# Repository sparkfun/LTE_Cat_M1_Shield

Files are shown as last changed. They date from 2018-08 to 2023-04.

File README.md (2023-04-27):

SparkFun LTE CAT M1/NB-IoT Shield - SARA-R4
========================================

SparkFun LTE CAT M1/NB-IoT Shield - SARA-R4 (https://www.sparkfun.com/products/14997)

[*SparkFun LTE CAT M1/NB-IoT Shield - SARA-R4 (CEL-14997)*](https://www.sparkfun.com/products/14997)

Arduino shield featuring a SARA-R410M-02B module, which supports both Cat M1 and NB-IoT

Repository Contents
-------------------

* **/Documentation** - Data sheets, additional product information
* **/Hardware** - Eagle design files (.brd, .sch)
* **/Production** - Production panel files (.brd)

Documentation
--------------
* **[Installing an Arduino Library Guide](https://learn.sparkfun.com/tutorials/installing-an-arduino-library)** - Basic information on how to install an Arduino library.
* **[Library](https://github.com/sparkfun/SparkFun_LTE_Shield_Arduino_Library)** - Arduino library.
* **[Hookup Guide](https://learn.sparkfun.com/tutorials/lte-cat-m1nb-iot-shield-hookup-guide)** - Basic hookup guide.

Version History
---------------
* v11 - Removed `GND` connection to `AREF` pin
* [v10](https://github.com/sparkfun/LTE_Cat_M1_Shield/releases/tag/v10) - Initial Release

License Information
-------------------

This product is _**open source**_! 

Various bits of the code have different licenses applied. Anything SparkFun wrote is beerware; if you see me (or any other SparkFun employee) at the local, and you've found our code helpful, please buy us a round!

Please use, reuse, and modify these files as you see fit. Please maintain attribution to SparkFun Electronics and release anything derivative under the same license.

Distributed as-is; no warranty is given.

- Your friends at SparkFun.

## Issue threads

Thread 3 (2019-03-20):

Both Sides of TVS tied to ground

method-nick, 2019-03-20:
I'm curious about your wiring of the TVS diode on the SIM card. By connecting both GND and VCC of the diode to the PCB ground the signals can't won't be able to get above the forward voltage of the diodes (1V).

I think the VCC pin of the diode should be connected to the 3V3 rail for correct operation.

lewispg228, 2019-12-09:
Hi @method-nick

Thanks for bringing this up. Sorry our response is so slow on this. Sorry for the confusion, but the part value in the schematic for this (v10) is incorrect.

The part shown in the schematic is "DT1042-04SO"
[DT1042-04SO datasheet](https://www.diodes.com/assets/Datasheets/DT1042-04SO.pdf)

This part is normally used as a unidirectional TVS circuit (which involves connecting to VCC).

In production we are populating a different part. We are actually using the "ESDA6V1BC6".
[ESDA6V1BC6 datasheet](https://static6.arrow.com/aropdfconversion/8da17f9020eacc1aa29eff2b41ce2f0dfe2e4561/cd0000190.pdf)

This part is used as a bidirectional TVS circuit, and so both pins 2 and 5 of the IC are intended to be connected to GND.

I found some interested articles regarding TVS circuits, if you'd like to read more on this:

[TI FORUM: Should TVS diodes be connected on the Vcc side](https://e2e.ti.com/support/interface/f/138/t/710604)

[TI APP NOTE: Design considerations for system-level
ESD circuit protection](https://www.ti.com/lit/an/slyt492/slyt492.pdf)
(particularly page 3, which describes the difference between unidirectional and bidirection TVS circuits)

Thanks again and we will work to get the part name in the schematic updated in v10 asap.
-Pete

Closed 2019-12-09.

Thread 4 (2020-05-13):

Use as cellular modem

sagilar, 2020-05-13:
I like to ask if there is the possibility to use the shield as a cellular modem, to provide connectivity, even if it is very slow, just to access services on the web.
I am using a board similar to a Raspberry PI, and I'd like to integrate this shield with the board to get internet access via the cellular module, and then, create a bridge between this interface (either via USB or Serial) and the wireless interface wlan0. So, I could set up a Wireless Access Point between cellular interface and WiFi.

Thanks for your answer.

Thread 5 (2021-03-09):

Teensy 4.x + SARA-R410 + TinyGSM + SSLClient  = failed mTLS connections?

MaffooClock, 2021-03-09:
I'm prototyping a project that is designed to communicate with [AWS IoT MQTT](https://docs.aws.amazon.com/iot/latest/developerguide/mqtt.html) via cellular IoT.  Using the MQTT service through AWS means mTLS is required, and the only library that can provide that for Arduino is [SSLClient](https://github.com/OPEnSLab-OSU/SSLClient).

It seems that when combining a u-blox SARA-R410 (or, perhaps more specifically, this SparkFun shield) with a Teensy 4.x, mTLS connections never complete.  I opened[ issue #33](https://github.com/OPEnSLab-OSU/SSLClient/issues/33) with SSLClient thinking the problem was with the library, but after switching to another modem (same codebase), the problem went away.

I've used the same SARA-R410 with other Arduinos (SAMD21 and SAM3X MCUs) with the same codebase with plenty of success, but for some strange reason, this particular shield seemed to cause a problem with SSLClient on the Teensy 4.x.

The only reason I'm opening this issue is just in case someone else happens to experience the same trouble I did with the same environment.  Maybe this is a highly unique situation that only I will ever experience, or perhaps my SparkFun shield is somehow defective (unlikely, seems to work fine otherwise), but I figured I had an obligation to share.

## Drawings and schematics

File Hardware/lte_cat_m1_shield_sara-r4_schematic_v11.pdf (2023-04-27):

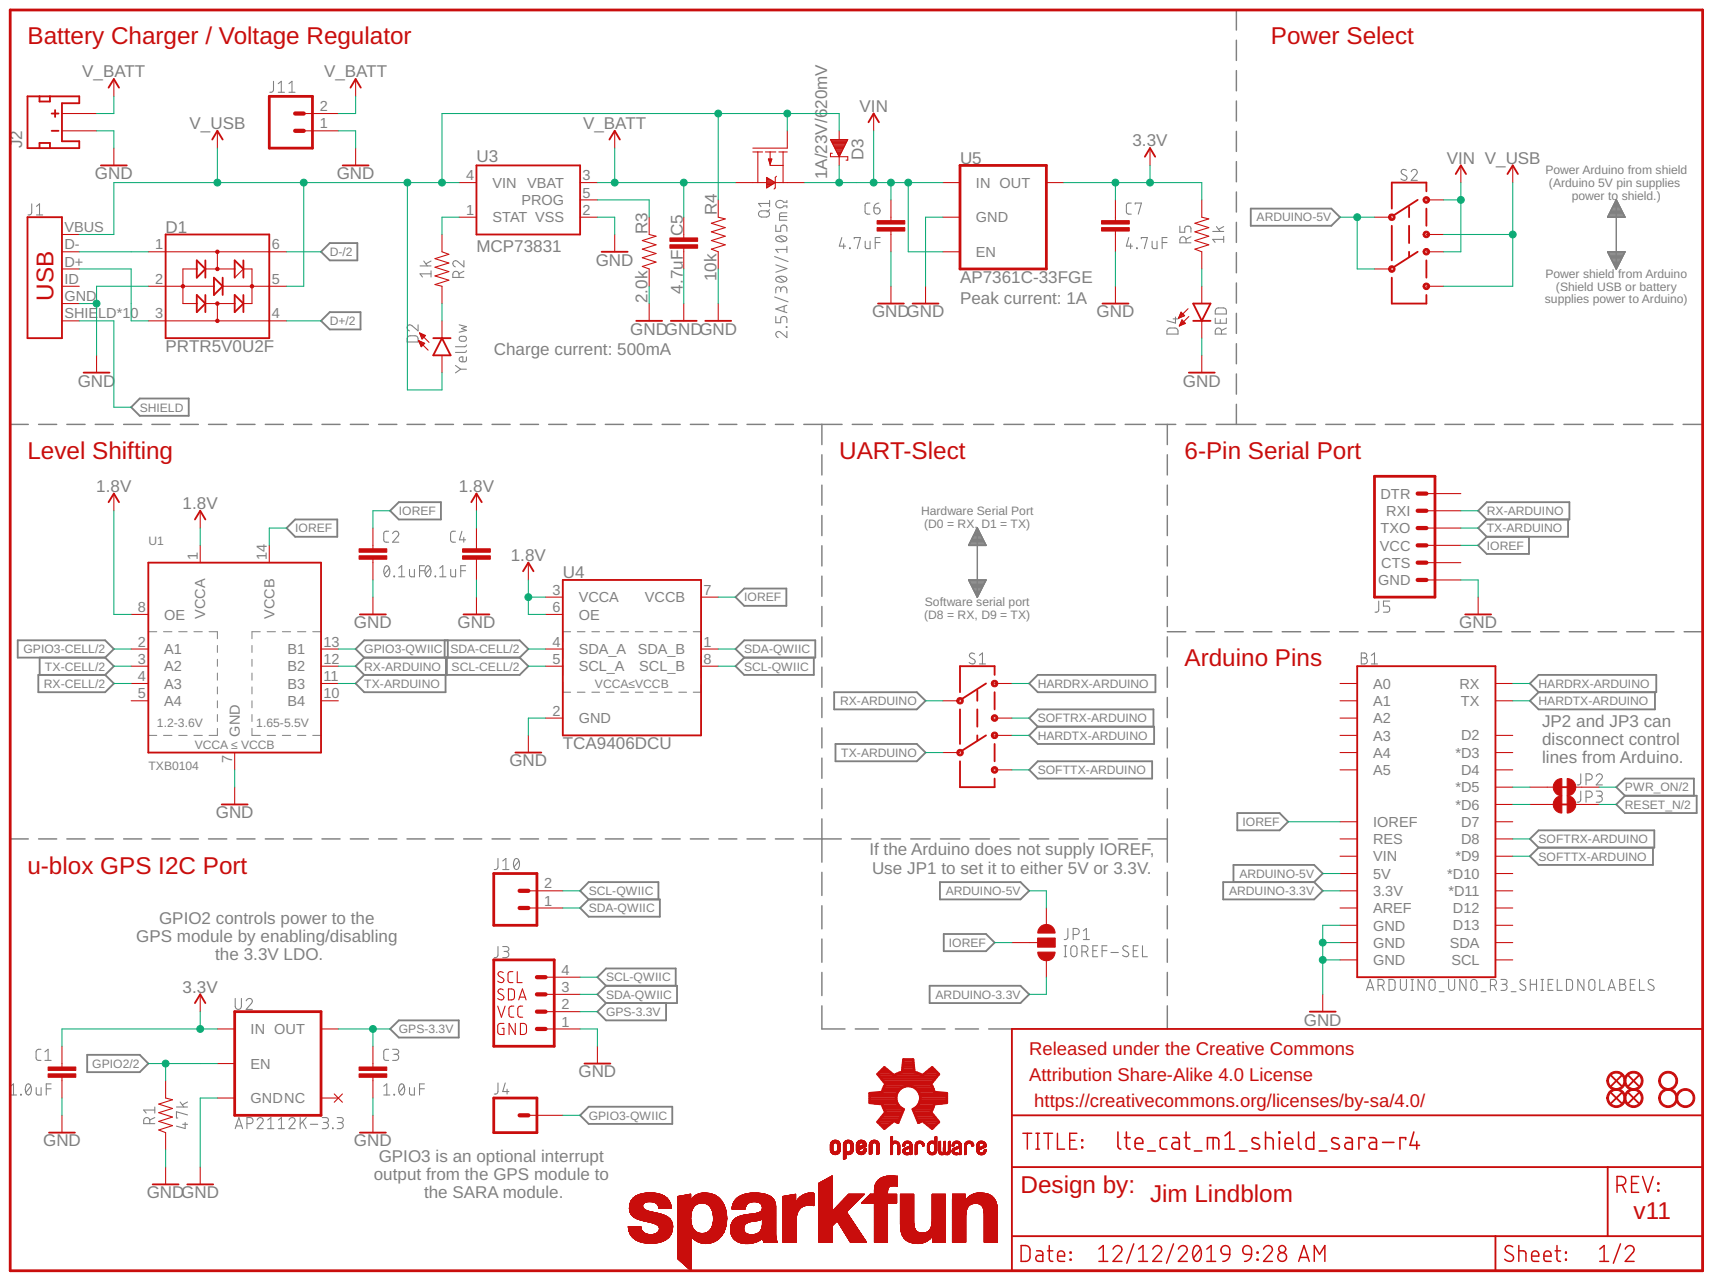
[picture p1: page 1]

Power Arduino from shield
(Arduino 5V pin supplies power to shield.) Power shield from Arduino

(Shield USB or battery
supplies power to Arduino)

Hardware Serial Port (D0 = RX, D1 = TX) Software serial port (D8 = RX, D9 = TX)

If the Arduino does not supply IOREF, Use JP1 to set it to either 5V or 3.3V. GPIO2 controls power to the GPS module by enabling/disabling

Released under the Creative Commons
Attribution Share-Alike 4.0 License
https://creativecommons.org/licenses/by-sa/4.0/

GPIO3 is an optional interrupt output from the GPS module to

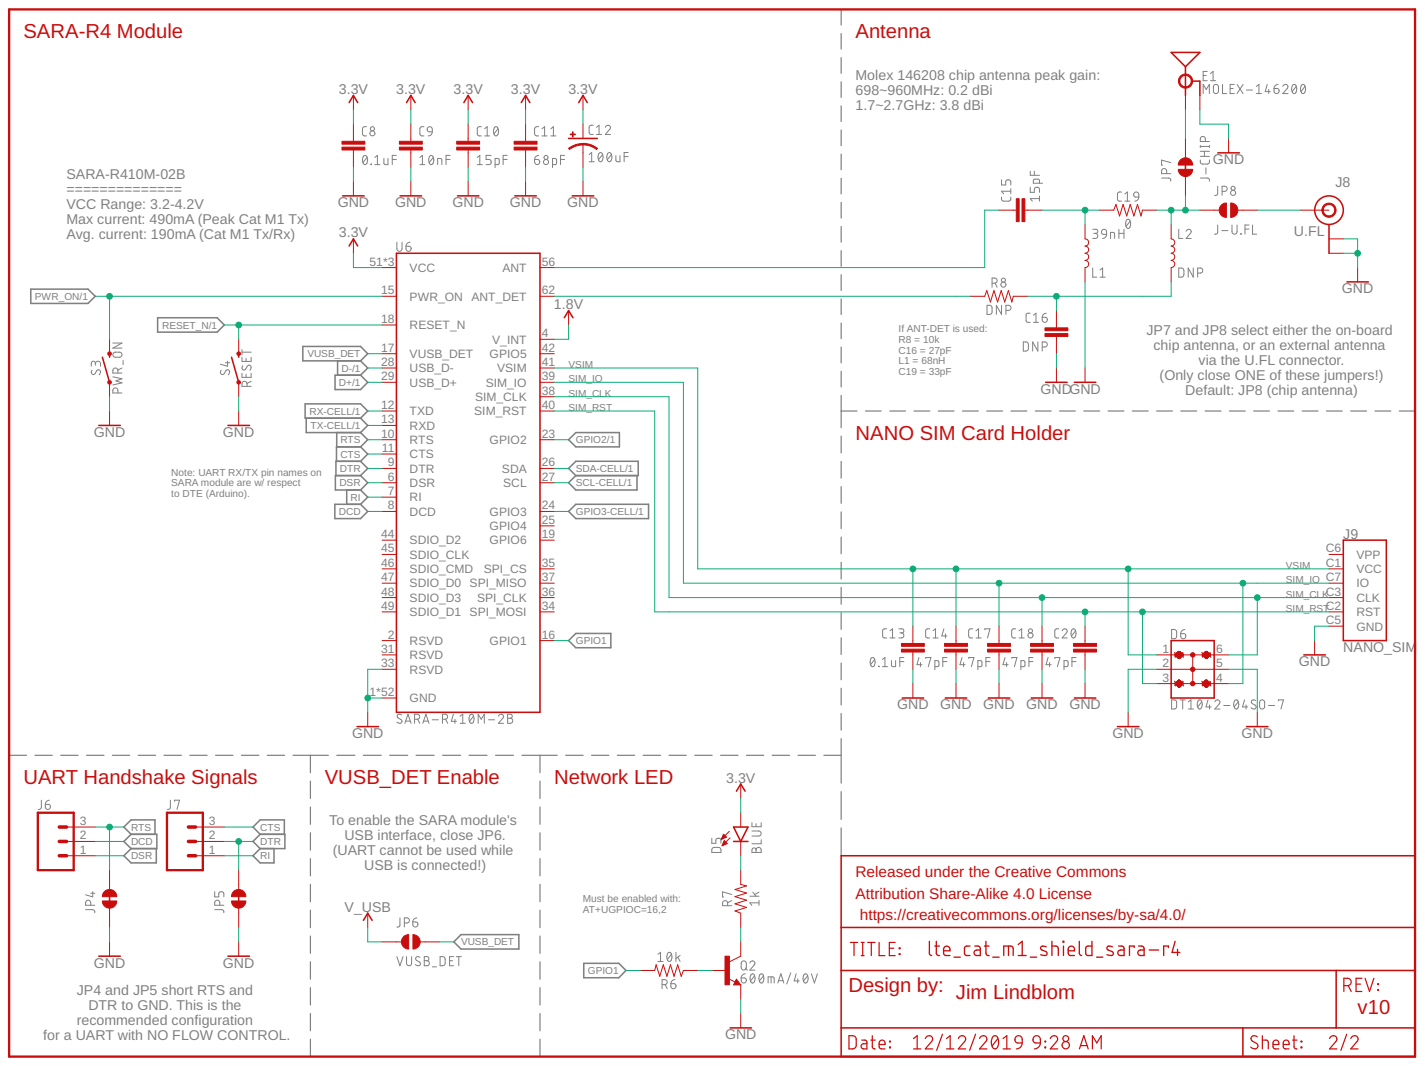
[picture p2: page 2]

Molex 146208 chip antenna peak gain: 698~960MHz: 0.2 dBi

Max current: 490mA (Peak Cat M1 Tx)
Avg. current: 190mA (Cat M1 Tx/Rx)

If ANT-DET is used: R8 = 10k C16 = 27pF

JP7 and JP8 select either the on-board
chip antenna, or an external antenna
via the U.FL connector. (Only close ONE of these jumpers!)

Default: JP8 (chip antenna) Note: UART RX/TX pin names on SARA module are w/ respect

NANO SIM Card Holder

GND GND GND GND GND

To enable the SARA module's USB interface, close JP6. (UART cannot be used while USB is connected!)

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

Must be enabled with: AT+UGPIOC=16,2

JP4 and JP5 short RTS and
DTR to GND. This is the
recommended configuration
for a UART with NO FLOW CONTROL.

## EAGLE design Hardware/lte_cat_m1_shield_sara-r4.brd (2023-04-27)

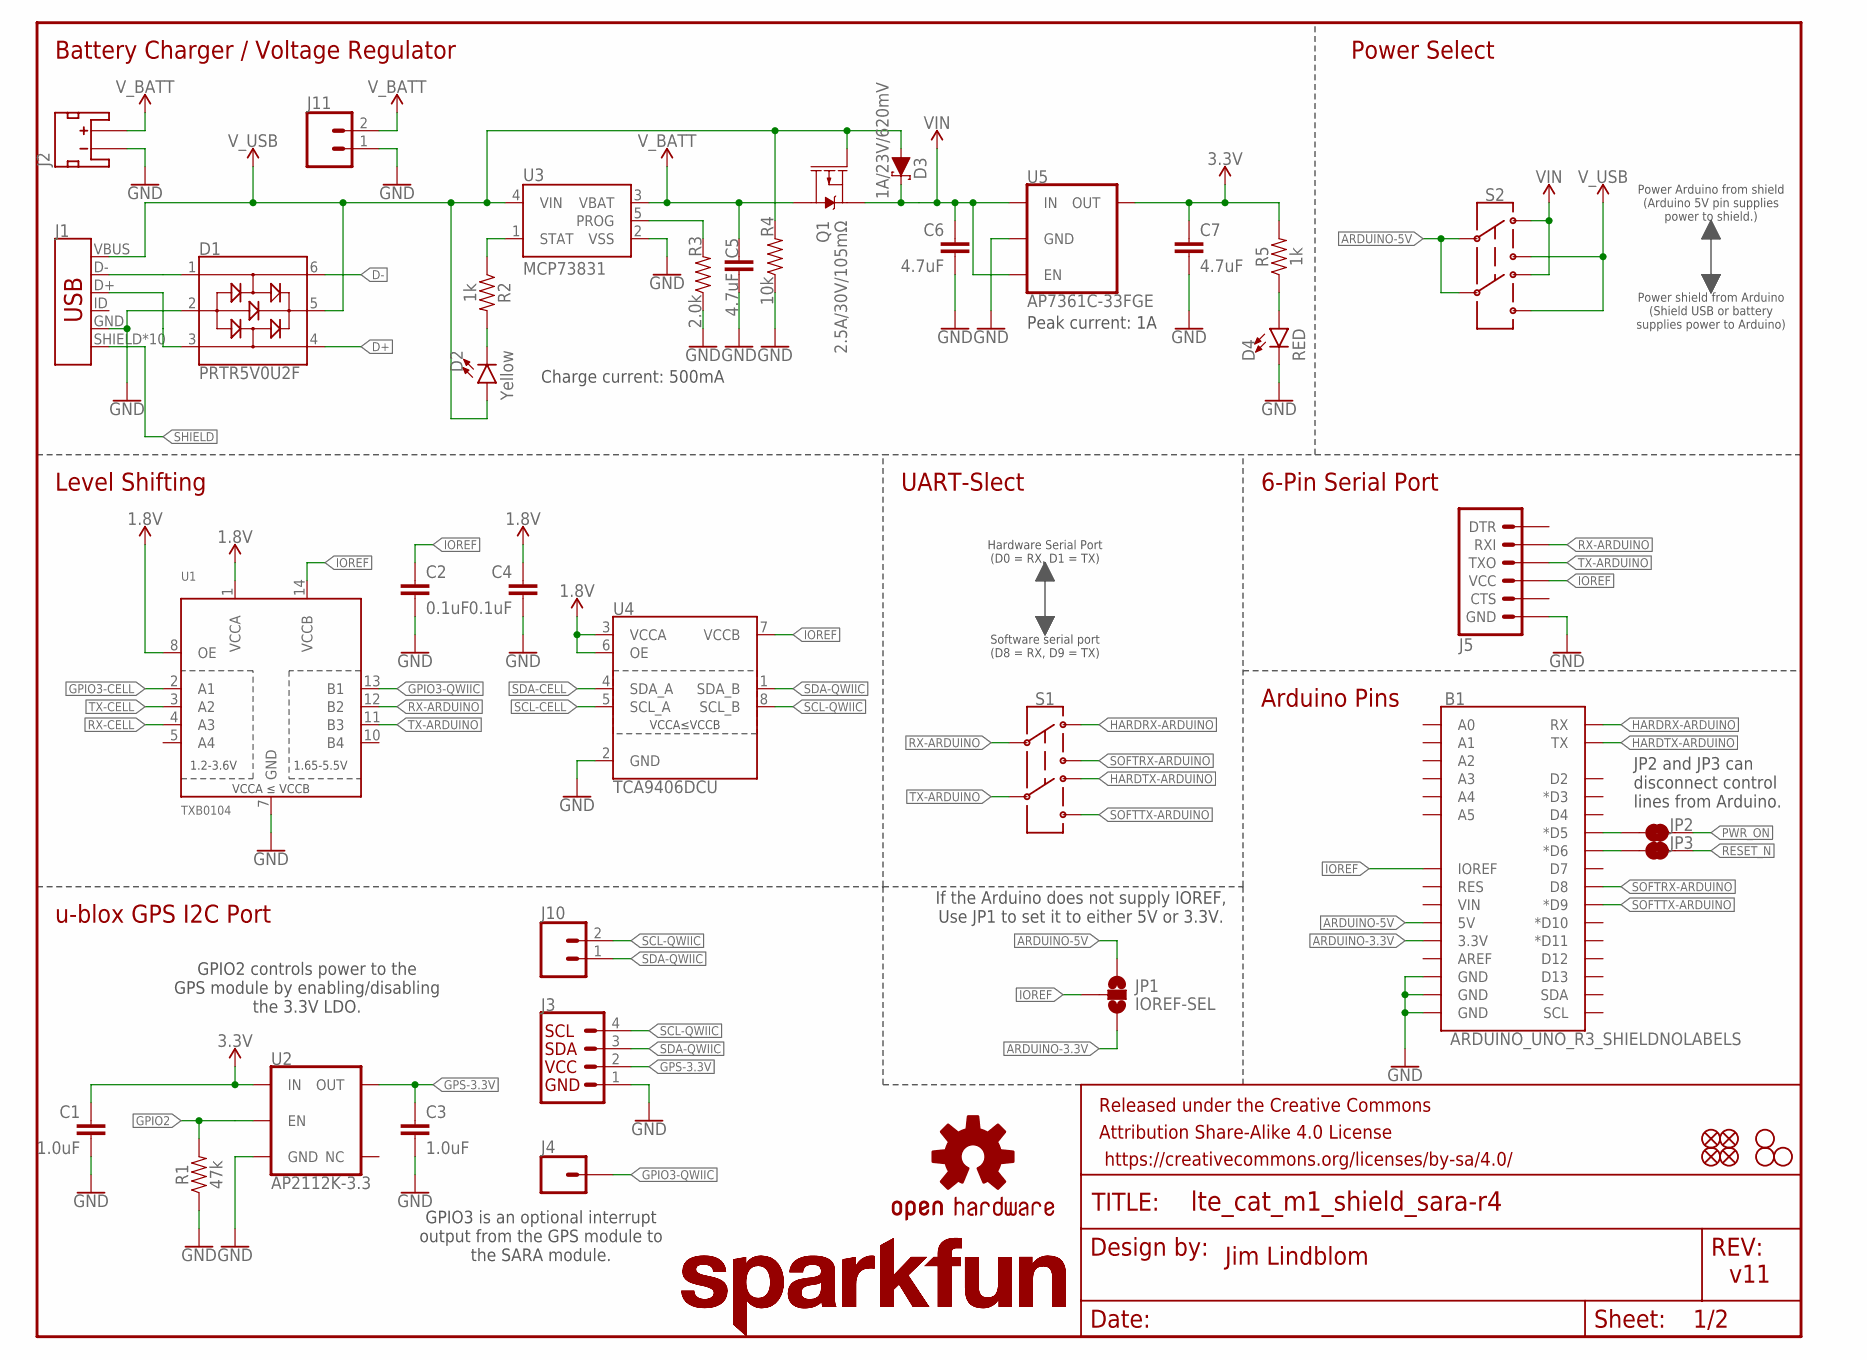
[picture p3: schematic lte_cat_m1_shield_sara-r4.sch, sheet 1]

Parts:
B1: ARDUINO_UNO_R3_SHIELDNOLABELS; UNO_R3_SHIELD_NOLABELS
C1, C3: 1.0uF; 0603
C2, C4: 0.1uF; 0603
C5, C6, C7: 4.7uF; 0603
D1: PRTR5V0U2F; SOT886
D2: Yellow; LED-0603
D3: 1A/23V/620mV; SOD-323
D4: RED; LED-0603
FD1, FD2, FD3, FD4: FIDUCIALUFIDUCIAL; FIDUCIAL-MICRO
FRAME1: FRAME-LETTER; CREATIVE_COMMONS
H1, H2, H3: STAND-OFF
J1: USB_MICRO-B_HALF_PTH_MILL; USB-MICROB-PTH-MILL
J2: JST_2MM_MALESMD; JST-2-SMD
J3: QWIIC_CONNECTORJS-1MM; 1X04_1MM_RA
J4: CONN_01PTH_NO_SILK_YES_STOP; 1X01_NO_SILK
J5: 6_PIN_SERIAL_TARGETNO_SILK; 1X06_NO_SILK
J10, J11: CONN_021X02_NO_SILK; 1X02_NO_SILK
JP1: IOREF-SEL; SMT-JUMPER_3_NO_SILK
JP2, JP3: JUMPER-SMT_2_NC_TRACE_SILK; SMT-JUMPER_2_NC_TRACE_SILK
LOGO1, LOGO3: SFE_LOGO_NAME.2_INCH; SFE_LOGO_NAME_.2
LOGO2: OSHW-LOGOM; OSHW-LOGO-M
Q1: 2.5A/30V/105mΩ; SOT23-3
R1: 47k; 0603
R2, R5: 1k; 0603
R3: 2.0k; 0603
R4: 10k; 0603
S1, S2: SWITCH-DPDT-SMD-AYZ0202; SWITCH_DPDT_SMD_AYZ0202
U1: TXB0104; TSSOP14
U2: AP2112K-3.3; SOT23-5
U3: MCP73831; SOT23-5
U4: TCA9406DCU; VSSOP-8
U5: AP7361C-33FGE; 8-UDFN

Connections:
1.8V: C4.1, U1.1 (VCCA), U1.8 (OE), U4.3 (VCCA), U4.6 (OE); also elsewhere on the board
3.3V: C1.1, C7.1, R5.2, U2.1 (IN), U5.1 (OUT); also elsewhere on the board
ARDUINO-3.3V: B1.3.3V, JP1.3
ARDUINO-5V: B1.5V, JP1.1, S2.2, S2.5
D+: D1.4; also elsewhere on the board
D-: D1.6; also elsewhere on the board
GND: B1.GND@0 (GND), B1.GND@1 (GND), B1.GND@2 (GND), C1.2, C2.2, C3.2, C4.2, C5.2, C6.2, C7.2, D1.2, D4.C, J1.GND, J2.1 (-), J3.1, J5.6 (GND), J11.1, R1.1, R3.1, R4.1, U1.7 (GND), U2.2 (GND), U3.2 (VSS), U4.2 (GND), U5.4 (GND), U5.EP (GND); also elsewhere on the board
GPIO2: R1.2, U2.3 (EN); also elsewhere on the board
GPIO3-CELL: U1.2 (A1); also elsewhere on the board
GPIO3-QWIIC: J4.1, U1.13 (B1)
GPS-3.3V: C3.1, J3.2, U2.5 (OUT)
HARDRX-ARDUINO: B1.RX, S1.1
HARDTX-ARDUINO: B1.TX, S1.4
IOREF: B1.IOREF, C2.1, J5.4 (VCC), JP1.2, U1.14 (VCCB), U4.7 (VCCB)
unnamed: R3.2, U3.5 (PROG)
unnamed: D1.1, J1.D-
unnamed: D1.3, J1.D+
unnamed: D4.A, R5.1
unnamed: D2.C, R2.2
unnamed: R2.1, U3.1 (STAT)
unnamed: B1.D5 (*D5), JP2.1
unnamed: B1.D6 (*D6), JP3.1
PWR_ON: JP2.2; also elsewhere on the board
RESET_N: JP3.2; also elsewhere on the board
RX-ARDUINO: J5.2 (RXI), S1.2, U1.12 (B2)
RX-CELL: U1.4 (A3); also elsewhere on the board
SCL-CELL: U4.5 (SCL_A); also elsewhere on the board
SCL-QWIIC: J3.4, J10.2, U4.8 (SCL_B)
SDA-CELL: U4.4 (SDA_A); also elsewhere on the board
SDA-QWIIC: J3.3, J10.1, U4.1 (SDA_B)
SHIELD: J1.SHIELD, J1.SHIELD2 (SHIELD), J1.SHIELD3 (SHIELD), J1.SHIELD4 (SHIELD), J1.SHIELD5 (SHIELD), J1.SHIELD6 (SHIELD), J1.SHIELD7 (SHIELD), J1.SHIELD8 (SHIELD), J1.SHIELD9 (SHIELD), J1.SHIELD10 (SHIELD)
SOFTRX-ARDUINO: B1.D8, S1.3
SOFTTX-ARDUINO: B1.D9 (*D9), S1.6
TX-ARDUINO: J5.3 (TXO), S1.5, U1.11 (B3)
TX-CELL: U1.3 (A2); also elsewhere on the board
VIN: C6.1, D3.C, Q1.2 (S), S2.1, S2.4, U5.5 (EN), U5.8 (IN)
V_BATT: C5.1, J2.2 (+), J11.2, Q1.3 (D), U3.3 (VBAT)
V_USB: D1.5, D2.A, D3.A, J1.VBUS, Q1.1 (G), R4.2, S2.3, S2.6, U3.4 (VIN); also elsewhere on the board

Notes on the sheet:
Charge current: 500mA
Power Arduino from shield (Arduino 5V pin supplies power to shield.)
Power shield from Arduino (Shield USB or battery supplies power to Arduino)
Battery Charger / Voltage Regulator
Power Select
Level Shifting
If the Arduino does not supply IOREF, Use JP1 to set it to either 5V or 3.3V.
u-blox GPS I2C Port
GPIO2 controls power to the GPS module by enabling/disabling the 3.3V LDO.
GPIO3 is an optional interrupt output from the GPS module to the SARA module.
UART-Slect
6-Pin Serial Port
Arduino Pins
Jim Lindblom
v11
Peak current: 1A
Hardware Serial Port (D0 = RX, D1 = TX)
Software serial port (D8 = RX, D9 = TX)
JP2 and JP3 can disconnect control lines from Arduino.

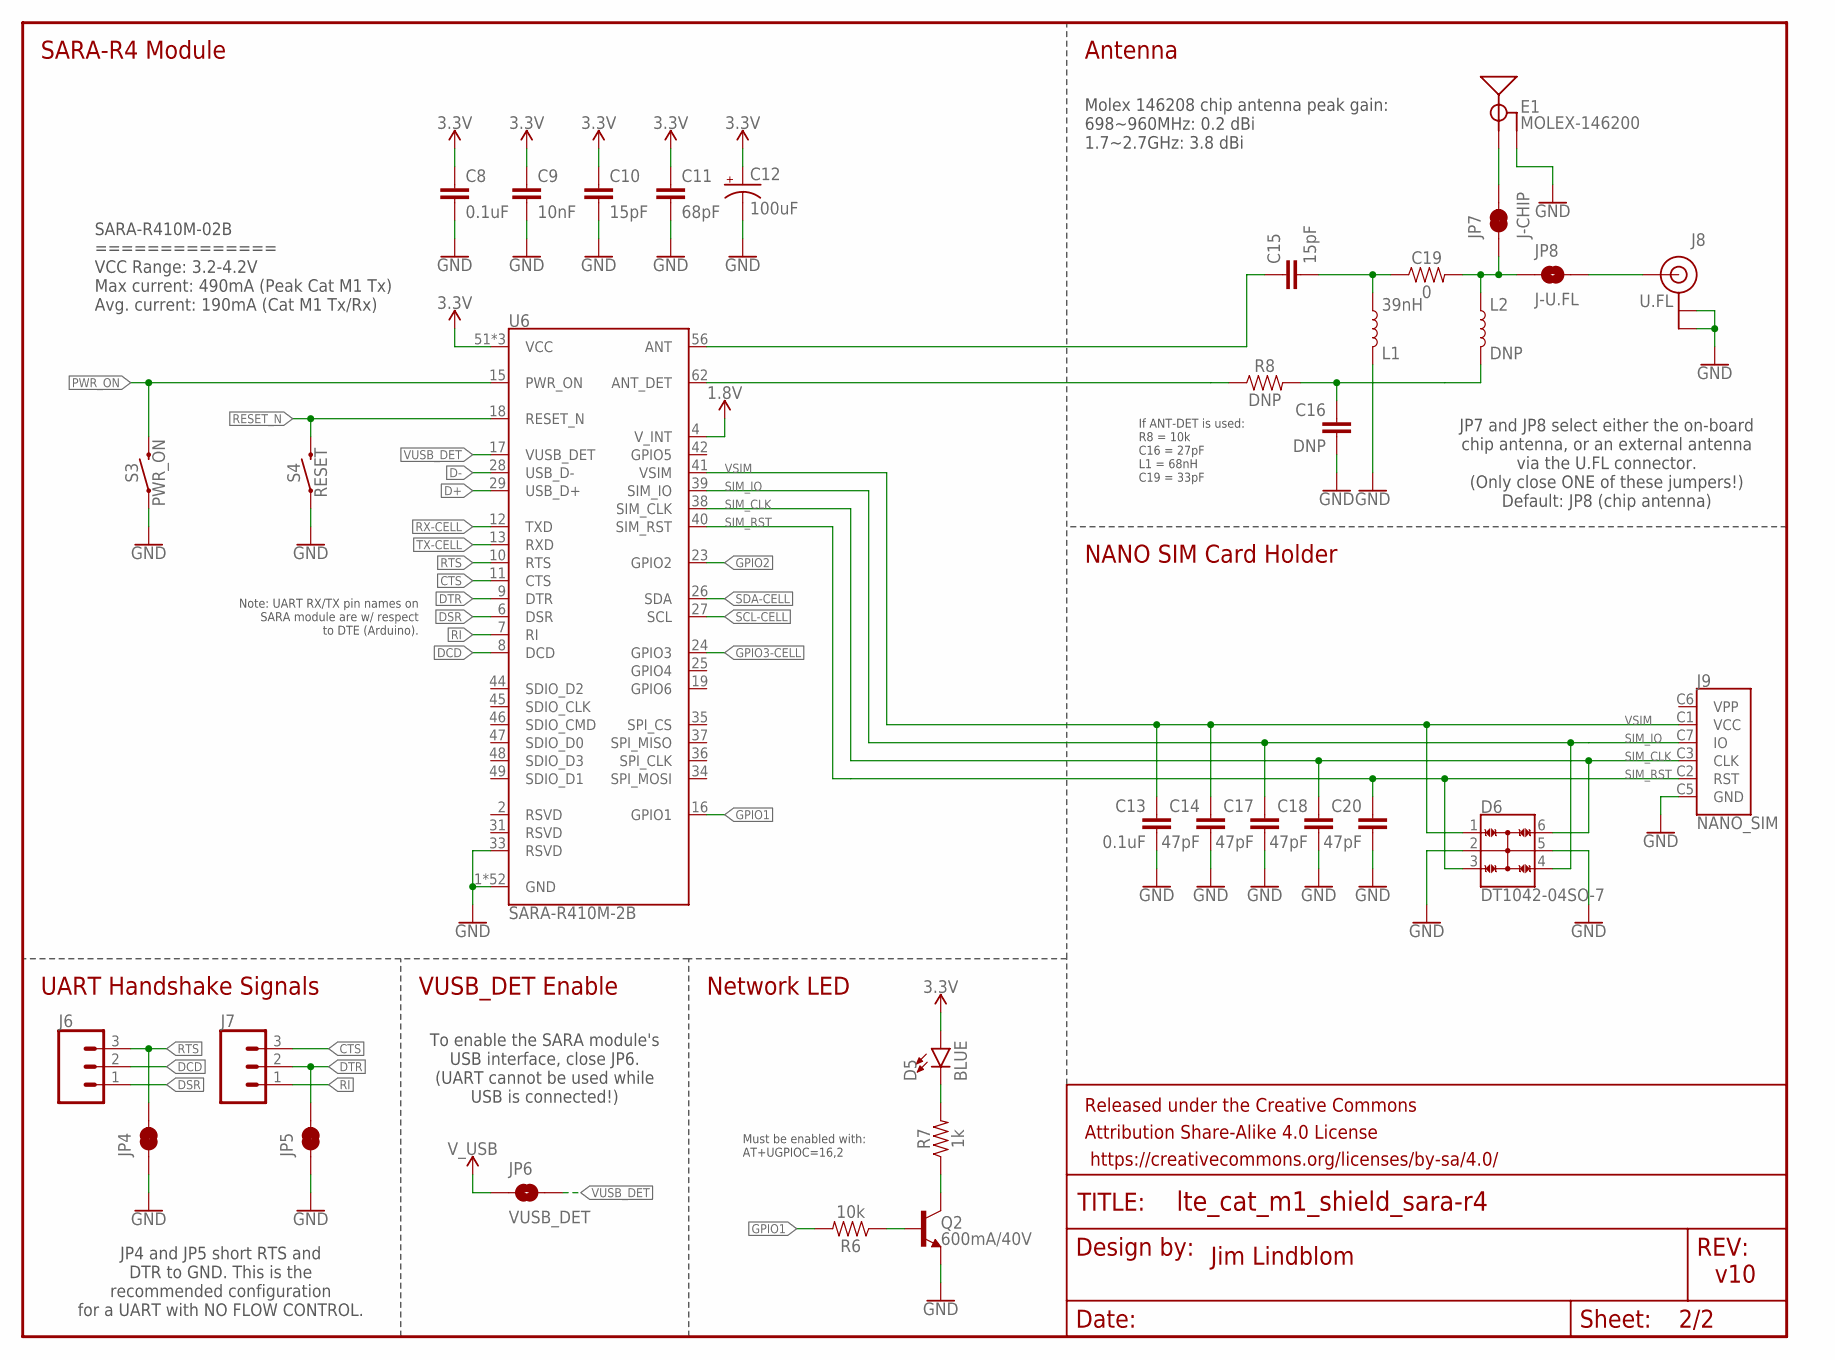
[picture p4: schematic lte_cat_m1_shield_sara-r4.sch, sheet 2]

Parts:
C8, C13: 0.1uF; 0603
C9: 10nF; 0603
C10, C15: 15pF; 0603
C11: 68pF; 0603
C12: 100uF; 1206-POLAR
C14, C17, C18, C20: 47pF; 0603
C16: DNP; 0603
C19: 0; 0603
D5: BLUE; LED-0603
D6: DT1042-04SO-7; SOT23-6L
E1: MOLEX-146200; MOLEX_146200
FRAME2: FRAME-LETTER; CREATIVE_COMMONS
J6, J7: CONN_031X03_NO_SILK; 1X03_NO_SILK
J8: U.FL
J9: NANO_SIM; NANO_SIM_WURTH_693043020611
JP4, JP5: JUMPER-SMT_2_NC_TRACE_SILK; SMT-JUMPER_2_NC_TRACE_SILK
JP6: VUSB_DET; SMT-JUMPER_2_NO_SILK
JP7: J-CHIP; SMT-JUMPER_2_NC_TRACE_NO-SILK
JP8: J-U.FL; SMT-JUMPER_2_NO_NO-SILK
L1: 39nH; 0603
L2: DNP; 0603
Q2: 600mA/40V; SOT23-3
R6: 10k; 0603
R7: 1k; 0603
R8: DNP; 0603
S3: PWR_ON; TACTILE_SWITCH_SMD_5.2MM
S4: RESET; TACTILE_SWITCH_SMD_5.2MM
U6: SARA-R410M-2B; SARA-LGA

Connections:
1.8V: U6.4 (V_INT); also elsewhere on the board
3.3V: C8.1, C9.1, C10.1, C11.1, C12.1 (+), D5.A, U6.51 (VCC), U6.52 (VCC), U6.53 (VCC); also elsewhere on the board
ANT: C15.1, U6.56 (ANT)
ANT_DET: R8.1, U6.62 (ANT_DET)
CTS: J7.3, U6.11 (CTS)
D+: U6.29 (USB_D+); also elsewhere on the board
D-: U6.28 (USB_D-); also elsewhere on the board
DCD: J6.2, U6.8 (DCD)
DSR: J6.1, U6.6 (DSR)
DTR: J7.2, JP5.2, U6.9 (DTR)
GND: C8.2, C9.2, C10.2, C11.2, C12.2 (-), C13.2, C14.2, C16.2, C17.2, C18.2, C20.2, D6.2, D6.5, E1.GND, J8.1 (GND), J8.2 (GND), J9.C5 (GND), JP4.1, JP5.1, L1.1, Q2.2 (E), S3.1, S3.2 (1), S4.1, S4.2 (1), U6.1 (GND), U6.3 (GND), U6.5 (GND), U6.14 (GND), U6.20 (GND), U6.21 (GND), U6.22 (GND), U6.30 (GND), U6.32 (GND), U6.33 (RSVD), U6.43 (GND), U6.50 (GND), U6.54 (GND), U6.55 (GND), U6.57 (GND), U6.58 (GND), U6.59 (GND), U6.60 (GND), U6.61 (GND), U6.63 (GND), U6.64 (GND), U6.65 (GND), U6.66 (GND), U6.67 (GND), U6.68 (GND), U6.69 (GND), U6.70 (GND), U6.71 (GND), U6.72 (GND), U6.73 (GND), U6.74 (GND), U6.75 (GND), U6.76 (GND), U6.77 (GND), U6.78 (GND), U6.79 (GND), U6.80 (GND), U6.81 (GND), U6.82 (GND), U6.83 (GND), U6.84 (GND), U6.85 (GND), U6.86 (GND), U6.87 (GND), U6.88 (GND), U6.89 (GND), U6.90 (GND), U6.91 (GND), U6.92 (GND), U6.93 (GND), U6.94 (GND), U6.95 (GND), U6.96 (GND); also elsewhere on the board
GPIO1: R6.2, U6.16 (GPIO1)
GPIO2: U6.23 (GPIO2); also elsewhere on the board
GPIO3-CELL: U6.24 (GPIO3); also elsewhere on the board
unnamed: C16.1, L2.2, R8.2
unnamed: C15.2, C19.1, L1.2
unnamed: J8.FEED (SIGNAL), JP8.2
unnamed: Q2.1 (B), R6.1
unnamed: D5.C, R7.2
unnamed: Q2.3 (C), R7.1
unnamed: C19.2, JP7.1, JP8.1, L2.1
unnamed: E1.FEED (SIGNAL), JP7.2
PWR_ON: S3.3 (2), S3.4 (2), U6.15 (PWR_ON); also elsewhere on the board
RESET_N: S4.3 (2), S4.4 (2), U6.18 (RESET_N); also elsewhere on the board
RI: J7.1, U6.7 (RI)
RTS: J6.3, JP4.2, U6.10 (RTS)
RX-CELL: U6.12 (TXD); also elsewhere on the board
SCL-CELL: U6.27 (SCL); also elsewhere on the board
SDA-CELL: U6.26 (SDA); also elsewhere on the board
SIM_CLK: C18.1, D6.6, J9.C3 (CLK), U6.38 (SIM_CLK)
SIM_IO: C17.1, D6.4, J9.C7 (IO), U6.39 (SIM_IO)
SIM_RST: C20.1, D6.3, J9.C2 (RST), U6.40 (SIM_RST)
TX-CELL: U6.13 (RXD); also elsewhere on the board
VSIM: C13.1, C14.1, D6.1, J9.C1 (VCC), U6.41 (VSIM)
VUSB_DET: JP6.2, U6.17 (VUSB_DET)
V_USB: JP6.1; also elsewhere on the board

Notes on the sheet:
Antenna
SARA-R4 Module
UART Handshake Signals
VUSB_DET Enable
Network LED
To enable the SARA module's USB interface, close JP6. (UART cannot be used while USB is connected!)
JP4 and JP5 short RTS and DTR to GND. This is the recommended configuration for a UART with NO FLOW CONTROL.
NANO SIM Card Holder
JP7 and JP8 select either the on-board chip antenna, or an external antenna via the U.FL connector. (Only close ONE of these jumpers!) Default: JP8 (chip antenna)
Note: UART RX/TX pin names on SARA module are w/ respect to DTE (Arduino).
Molex 146208 chip antenna peak gain: 698~960MHz: 0.2 dBi 1.7~2.7GHz: 3.8 dBi
Jim Lindblom
v10
Must be enabled with: AT+UGPIOC=16,2
SARA-R410M-02B ============== VCC Range: 3.2-4.2V Max current: 490mA (Peak Cat M1 Tx) Avg. current: 190mA (Cat M1 Tx/Rx)
If ANT-DET is used: R8 = 10k C16 = 27pF L1 = 68nH C19 = 33pF

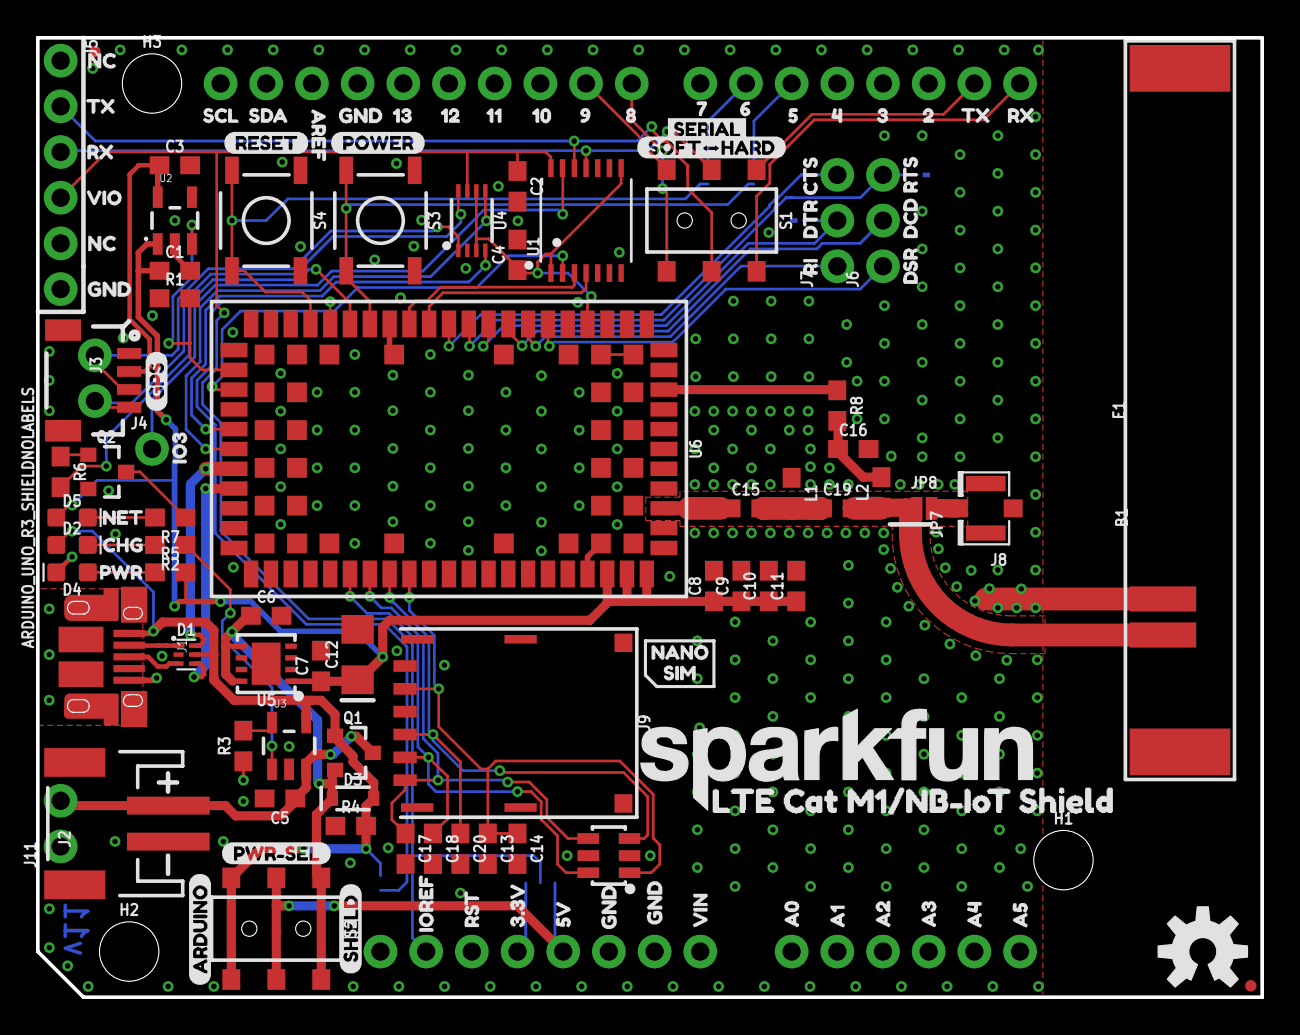
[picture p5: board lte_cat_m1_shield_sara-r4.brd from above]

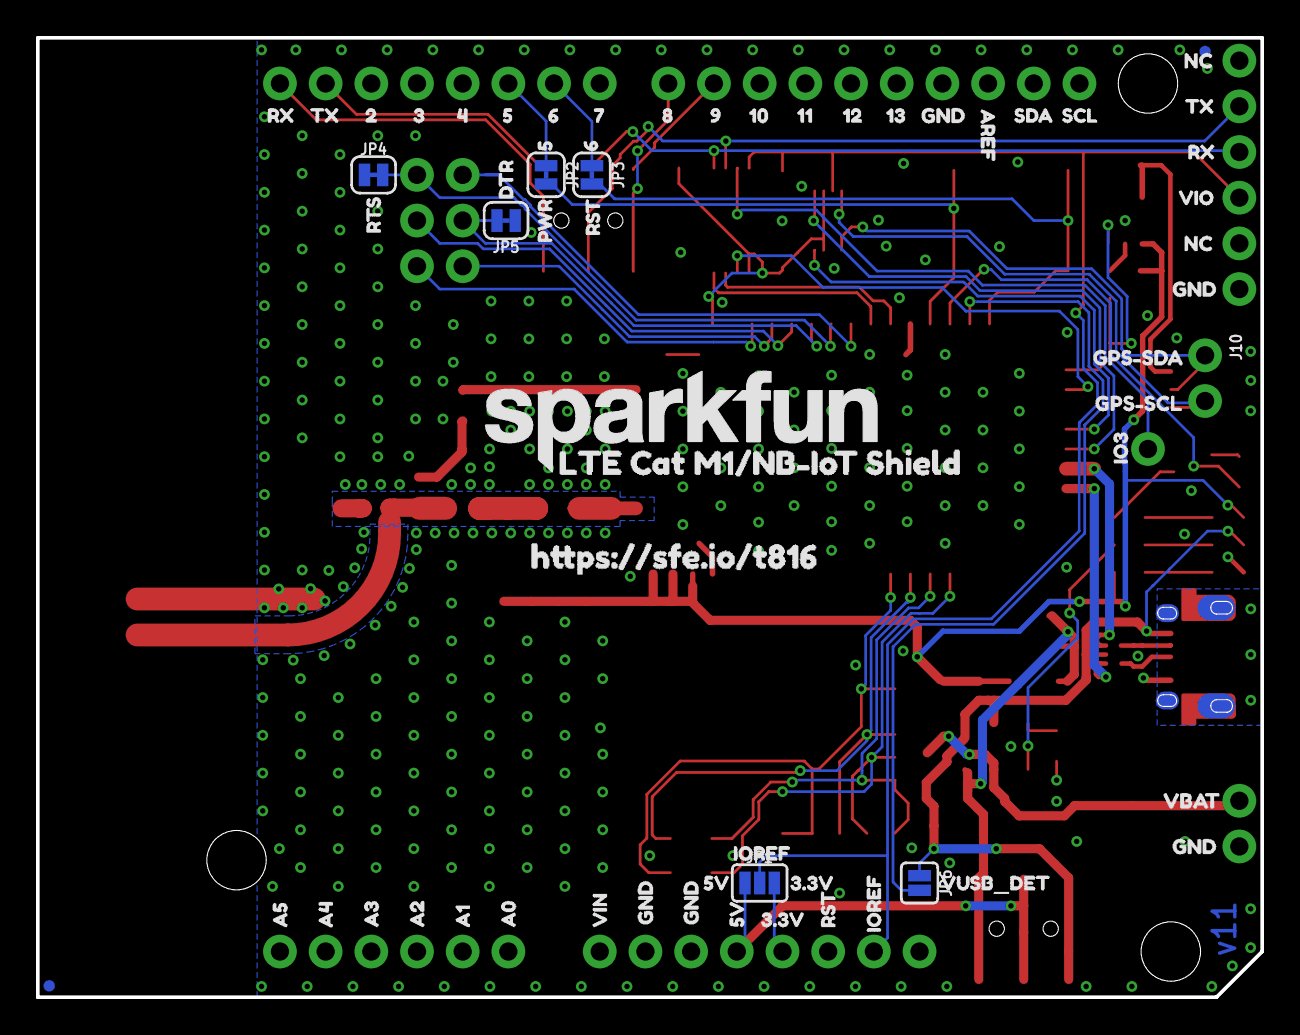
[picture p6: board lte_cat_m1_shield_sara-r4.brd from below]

Board: 2 copper layers, 68.1 x 53.3 mm, 193 parts (64 on the bottom side), 60 nets.

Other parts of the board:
U$1, U$85: SCL0
U$2, U$84: SDA1
U$3, U$86: AREF2
U$4, U$45, U$46, U$73, U$74, U$88, U$104, U$105, U$112: GND3
U$5, U$87: 134
U$6, U$89: 125
U$7, U$90: 116
U$8, U$91: 107
U$9, U$92: 98
U$10, U$93: 89
U$11: RESET48
U$12: GPS47
U$13, U$94: 714
U$14, U$62, U$95: 615
U$15, U$61, U$96: 516
U$16, U$97: 417
U$17, U$98: 318
U$18, U$99: 219
U$19: POWER49
U$20, U$30, U$81, U$101: RX22
U$21, U$31, U$80, U$100: TX21
U$22: SERIAL57
U$23: CTS23
U$24, U$63: DTR24
U$25: RI25
U$26: DSR26
U$27: DCD27
U$28, U$64: RTS28
U$29, U$82: VIO29
U$32, U$77: LTE_CAT_M1#NB#IOT_SHIELD1
U$33: ARDUINO51
U$34, U$79: IO334
U$35: NET31
U$36: CHG33
U$37, U$59: PWR32
U$38: PWR#SEL53
U$39: SHIELD52
U$40, U$42: RST0
U$41, U$56, U$78: IOREF39
U$43, U$58, U$76: 3#3V41
U$44, U$57, U$75: 5V42
U$47, U$72: VIN43
U$48, U$71: A044
U$49, U$70: A145
U$50, U$69: A246
U$51, U$68: A347
U$52, U$67: A448
U$53, U$66: A549
U$54: NANO50
U$55: SIM51
U$60: RST40
U$65: VUSB_DET52
U$83: HTTPS###SFE#IO#T8160
U$102: SOFT#HARD50
U$103, U$106, U$107, U$108: NC0
U$109: GPS#SCL1
U$110: GPS#SDA0
U$111: VBAT2

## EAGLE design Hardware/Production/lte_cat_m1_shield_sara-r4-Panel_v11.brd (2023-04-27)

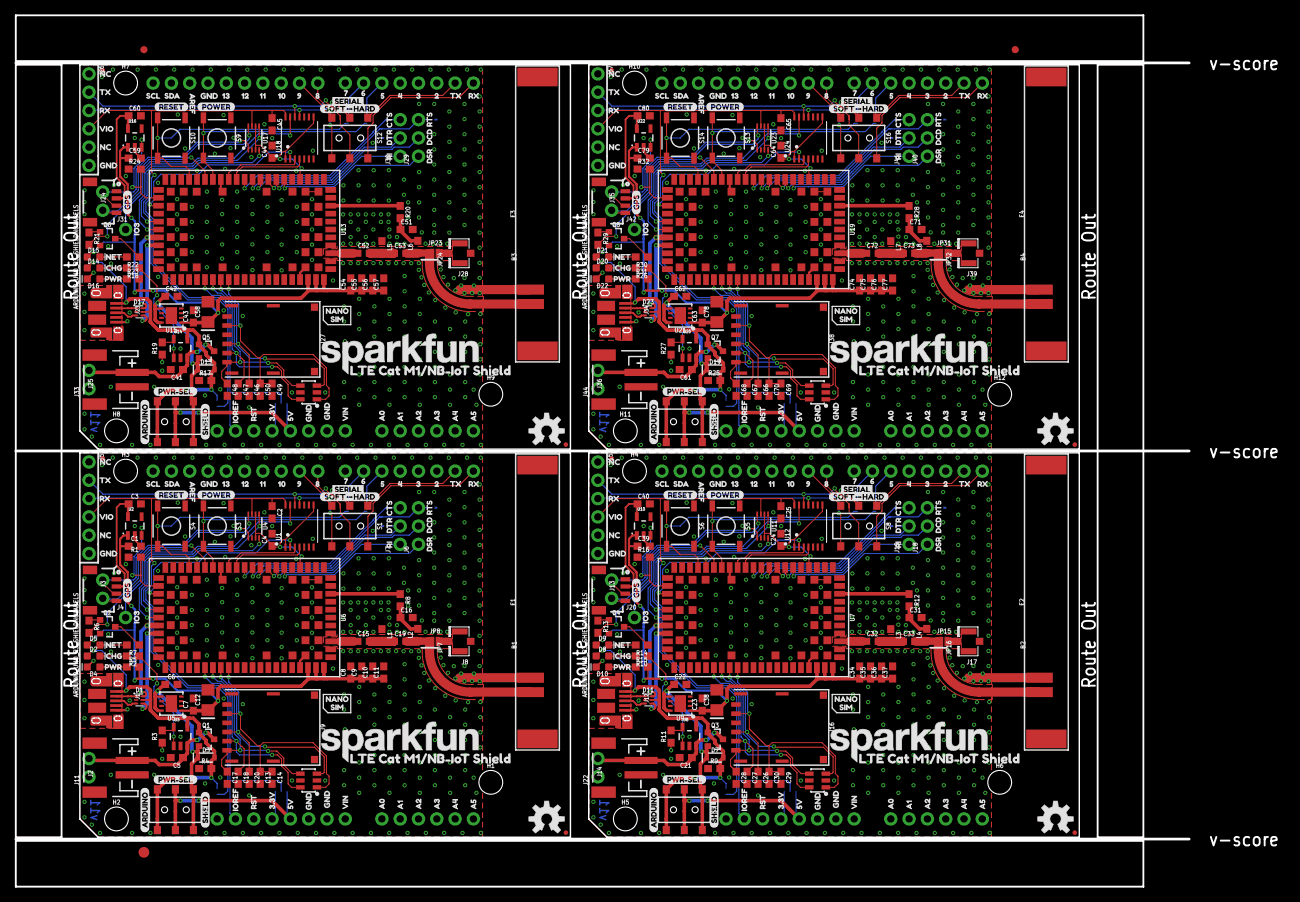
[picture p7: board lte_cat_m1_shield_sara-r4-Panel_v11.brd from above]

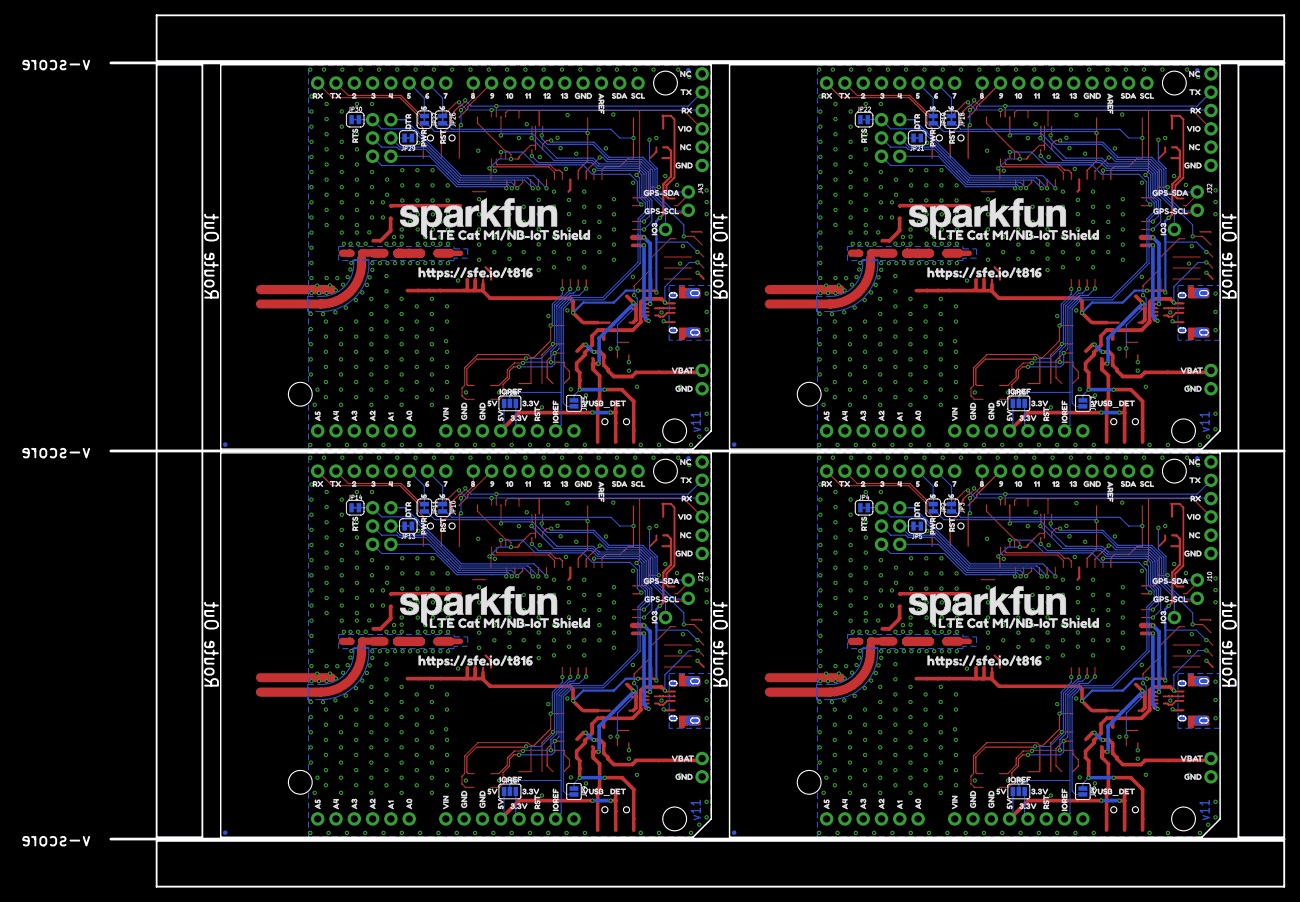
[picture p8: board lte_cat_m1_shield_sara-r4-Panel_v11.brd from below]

Board: 2 copper layers, 162.8 x 120.9 mm, 767 parts (256 on the bottom side), 240 nets.

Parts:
B1, B2, B3, B4: ARDUINO_UNO_R3_SHIELDNOLABELS; UNO_R3_SHIELD_NOLABELS
C1, C3, C39, C40, C59, C60, C79, C80: 1.0uF; 0603
C2, C4, C8, C13, C24, C25, C30, C34, C44, C45, C50, C54, C64, C65, C70, C74: 0.1uF; 0603
C5, C6, C7, C21, C22, C23, C41, C42, C43, C61, C62, C63: 4.7uF; 0603
C9, C35, C55, C75: 10nF; 0603
C10, C15, C32, C36, C52, C56, C72, C76: 15pF; 0603
C11, C37, C57, C77: 68pF; 0603
C12, C38, C58, C78: 100uF; 1206-POLAR
C14, C17, C18, C20, C26, C27, C28, C29, C46, C47, C48, C49, C66, C67, C68, C69: 47pF; 0603
C16, C31, C51, C71: DNP; 0603
C19, C33, C53, C73: 0; 0603
D1, D11, D17, D23: PRTR5V0U2F; SOT886
D2, D8, D14, D20: Yellow; LED-0603
D3, D7, D13, D19: 1A/23V/620mV; SOD-323
D4, D10, D16, D22: RED; LED-0603
D5, D9, D15, D21: BLUE; LED-0603
D6, D12, D18, D24: DT1042-04SO-7; SOT23-6L
E1, E2, E3, E4: MOLEX-146200; MOLEX_146200
E$1, E$2: FIDUCIAL-1X2
E$3: FIDUCIAL-1.5X3
FD1, FD2, FD3, FD4, FD5, FD6, FD7, FD8, FD9, FD10, FD11, FD12, FD13, FD14, FD15, FD16: FIDUCIALUFIDUCIAL; FIDUCIAL-MICRO
H1, H2, H3, H4, H5, H6, H7, H8, H9, H10, H11, H12: STAND-OFF
J1, J12, J23, J34: USB-MICROB-PTH-MILL
J2, J14, J25, J36: JST-2-SMD
J3, J13, J24, J35: 1X04_1MM_RA
J4, J20, J31, J42: 1X01_NO_SILK
J5, J15, J26, J37: 1X06_NO_SILK
J6, J7, J18, J19, J29, J30, J40, J41: 1X03_NO_SILK
J8, J17, J28, J39: U.FL
J9, J16, J27, J38: NANO_SIM; NANO_SIM_WURTH_693043020611
J10, J11, J21, J22, J32, J33, J43, J44: 1X02_NO_SILK
JP1, JP12, JP20, JP28: IOREF-SEL; SMT-JUMPER_3_NO_SILK
JP2, JP3, JP10, JP11, JP18, JP19, JP26, JP27: JUMPER-SMT_2_NC_TRACE_SILK; SMT-JUMPER_2_NC_TRACE_SILK
JP4, JP5, JP13, JP14, JP21, JP22, JP29, JP30: SMT-JUMPER_2_NC_TRACE_SILK
JP6, JP9, JP17, JP25: VUSB_DET; SMT-JUMPER_2_NO_SILK
JP7, JP16, JP24, JP32: J-CHIP; SMT-JUMPER_2_NC_TRACE_NO-SILK
JP8, JP15, JP23, JP31: J-U.FL; SMT-JUMPER_2_NO_NO-SILK
L1, L3, L5, L7: 39nH; 0603
L2, L4, L6, L8: DNP; 0603
LOGO1, LOGO3, LOGO5, LOGO6, LOGO8, LOGO9, LOGO11, LOGO12: SFE_LOGO_NAME.2_INCH; SFE_LOGO_NAME_.2
LOGO2, LOGO4, LOGO7, LOGO10: OSHW-LOGOM; OSHW-LOGO-M
Q1, Q3, Q5, Q7: 2.5A/30V/105mΩ; SOT23-3
Q2, Q4, Q6, Q8: 600mA/40V; SOT23-3
R1, R16, R24, R32: 47k; 0603
R2, R5, R7, R10, R14, R15, R18, R22, R23, R26, R30, R31: 1k; 0603
R3, R11, R19, R27: 2.0k; 0603
R4, R6, R9, R13, R17, R21, R25, R29: 10k; 0603
R8, R12, R20, R28: DNP; 0603
S1, S2, S7, S8, S11, S12, S15, S16: SWITCH_DPDT_SMD_AYZ0202
S3, S5, S9, S13: PWR_ON; TACTILE_SWITCH_SMD_5.2MM
S4, S6, S10, S14: RESET; TACTILE_SWITCH_SMD_5.2MM
U1, U12, U18, U24: TXB0104; TSSOP14
U2, U10, U16, U22: AP2112K-3.3; SOT23-5
U3, U8, U14, U20: MCP73831; SOT23-5
U4, U11, U17, U23: TCA9406DCU; VSSOP-8
U5, U9, U15, U21: AP7361C-33FGE; 8-UDFN
U6, U7, U13, U19: SARA-R410M-2B; SARA-LGA
U$1, U$85, U$113, U$185, U$225, U$297, U$337, U$409: SCL0
U$2, U$84, U$114, U$184, U$226, U$296, U$338, U$408: SDA1
U$3, U$86, U$115, U$186, U$227, U$298, U$339, U$410: AREF2
U$4, U$45, U$46, U$73, U$74, U$88, U$104, U$105, U$112, U$116, U$147, U$148, U$175, U$176, U$188, U$202, U$203, U$222, U$228, U$259, U$260, U$287, U$288, U$300, U$314, U$315, U$334, U$340, U$371, U$372, U$399, U$400, U$412, U$426, U$427, U$446: GND3
U$5, U$87, U$117, U$187, U$229, U$299, U$341, U$411: 134
U$6, U$89, U$118, U$189, U$230, U$301, U$342, U$413: 125
U$7, U$90, U$119, U$190, U$231, U$302, U$343, U$414: 116
U$8, U$91, U$120, U$191, U$232, U$303, U$344, U$415: 107
U$9, U$92, U$121, U$192, U$233, U$304, U$345, U$416: 98
U$10, U$93, U$122, U$193, U$234, U$305, U$346, U$417: 89
U$11, U$207, U$319, U$431: RESET48
U$12, U$208, U$320, U$432: GPS47
U$13, U$94, U$123, U$194, U$235, U$306, U$347, U$418: 714
U$14, U$62, U$95, U$124, U$164, U$195, U$236, U$276, U$307, U$348, U$388, U$419: 615
U$15, U$61, U$96, U$125, U$163, U$196, U$237, U$275, U$308, U$349, U$387, U$420: 516
U$16, U$97, U$126, U$197, U$238, U$309, U$350, U$421: 417
U$17, U$98, U$127, U$198, U$239, U$310, U$351, U$422: 318
U$18, U$99, U$128, U$199, U$240, U$311, U$352, U$423: 219
U$19, U$206, U$318, U$430: POWER49
U$20, U$30, U$81, U$101, U$129, U$138, U$182, U$201, U$241, U$250, U$294, U$313, U$353, U$362, U$406, U$425: RX22
U$21, U$31, U$80, U$100, U$130, U$139, U$181, U$200, U$242, U$251, U$293, U$312, U$354, U$363, U$405, U$424: TX21
U$22, U$205, U$317, U$429: SERIAL57
U$23, U$131, U$243, U$355: CTS23
U$24, U$63, U$132, U$165, U$244, U$277, U$356, U$389: DTR24
U$25, U$133, U$245, U$357: RI25
U$26, U$134, U$246, U$358: DSR26
U$27, U$135, U$247, U$359: DCD27
U$28, U$64, U$136, U$166, U$248, U$278, U$360, U$390: RTS28
U$29, U$82, U$137, U$183, U$249, U$295, U$361, U$407: VIO29
U$32, U$77, U$223, U$224, U$335, U$336, U$447, U$448: LTE_CAT_M1#NB#IOT_SHIELD1
U$33, U$209, U$321, U$433: ARDUINO51
U$34, U$79, U$140, U$180, U$252, U$292, U$364, U$404: IO334
U$35, U$141, U$253, U$365: NET31
U$36, U$142, U$254, U$366: CHG33
U$37, U$59, U$143, U$161, U$255, U$273, U$367, U$385: PWR32
U$38, U$211, U$323, U$435: PWR#SEL53
U$39, U$210, U$322, U$434: SHIELD52
U$40, U$42, U$212, U$213, U$324, U$325, U$436, U$437: RST0
U$41, U$56, U$78, U$144, U$158, U$179, U$256, U$270, U$291, U$368, U$382, U$403: IOREF39
U$43, U$58, U$76, U$145, U$160, U$178, U$257, U$272, U$290, U$369, U$384, U$402: 3#3V41
U$44, U$57, U$75, U$146, U$159, U$177, U$258, U$271, U$289, U$370, U$383, U$401: 5V42
U$47, U$72, U$149, U$174, U$261, U$286, U$373, U$398: VIN43
U$48, U$71, U$150, U$173, U$262, U$285, U$374, U$397: A044
U$49, U$70, U$151, U$172, U$263, U$284, U$375, U$396: A145
U$50, U$69, U$152, U$171, U$264, U$283, U$376, U$395: A246
U$51, U$68, U$153, U$170, U$265, U$282, U$377, U$394: A347
U$52, U$67, U$154, U$169, U$266, U$281, U$378, U$393: A448
U$53, U$66, U$155, U$168, U$267, U$280, U$379, U$392: A549
U$54, U$156, U$268, U$380: NANO50
U$55, U$157, U$269, U$381: SIM51
U$60, U$162, U$274, U$386: RST40
U$65, U$167, U$279, U$391: VUSB_DET52
U$83, U$214, U$326, U$438: HTTPS###SFE#IO#T8160
U$102, U$204, U$316, U$428: SOFT#HARD50
U$103, U$106, U$107, U$108, U$215, U$216, U$217, U$218, U$327, U$328, U$329, U$330, U$439, U$440, U$441, U$442: NC0
U$109, U$219, U$331, U$443: GPS#SCL1
U$110, U$220, U$332, U$444: GPS#SDA0
U$111, U$221, U$333, U$445: VBAT2

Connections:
1.8V: C4.1, U1.1, U1.8, U4.3, U4.6, U6.4
1.8V1: C24.1, U7.4, U11.3, U11.6, U12.1, U12.8
1.8V2: C44.1, U13.4, U17.3, U17.6, U18.1, U18.8
1.8V3: C64.1, U19.4, U23.3, U23.6, U24.1, U24.8
3.3V: C1.1, C7.1, C8.1, C9.1, C10.1, C11.1, C12.1, D5.A, R5.2, U2.1, U5.1, U6.51, U6.52, U6.53
3.3V1: C23.1, C34.1, C35.1, C36.1, C37.1, C38.1, C39.1, D9.A, R15.2, U7.51, U7.52, U7.53, U9.1, U10.1
3.3V2: C43.1, C54.1, C55.1, C56.1, C57.1, C58.1, C59.1, D15.A, R23.2, U13.51, U13.52, U13.53, U15.1, U16.1
3.3V3: C63.1, C74.1, C75.1, C76.1, C77.1, C78.1, C79.1, D21.A, R31.2, U19.51, U19.52, U19.53, U21.1, U22.1
ANT: C15.1, U6.56
ANT1: C32.1, U7.56
ANT2: C52.1, U13.56
ANT3: C72.1, U19.56
ANT_DET: R8.1, U6.62
ANT_DET1: R12.1, U7.62
ANT_DET2: R20.1, U13.62
ANT_DET3: R28.1, U19.62
ARDUINO-3.3V: B1.3.3V, JP1.3
ARDUINO-3.3V1: B2.3.3V, JP12.3
ARDUINO-3.3V2: B3.3.3V, JP20.3
ARDUINO-3.3V3: B4.3.3V, JP28.3
ARDUINO-5V: B1.5V, JP1.1, S2.2, S2.5
ARDUINO-5V1: B2.5V, JP12.1, S7.2, S7.5
ARDUINO-5V2: B3.5V, JP20.1, S11.2, S11.5
ARDUINO-5V3: B4.5V, JP28.1, S15.2, S15.5
CTS: J7.3, U6.11
CTS1: J19.3, U7.11
CTS2: J30.3, U13.11
CTS3: J41.3, U19.11
D+: D1.4, U6.29
D+1: D11.4, U7.29
D+2: D17.4, U13.29
D+3: D23.4, U19.29
D-: D1.6, U6.28
D-1: D11.6, U7.28
D-2: D17.6, U13.28
D-3: D23.6, U19.28
DCD: J6.2, U6.8
DCD1: J18.2, U7.8
DCD2: J29.2, U13.8
DCD3: J40.2, U19.8
DSR: J6.1, U6.6
DSR1: J18.1, U7.6
DSR2: J29.1, U13.6
DSR3: J40.1, U19.6
DTR: J7.2, JP5.2, U6.9
DTR1: J19.2, JP13.2, U7.9
DTR2: J30.2, JP21.2, U13.9
DTR3: J41.2, JP29.2, U19.9
GND: B1.GND@0, B1.GND@1, B1.GND@2, C1.2, C2.2, C3.2, C4.2, C5.2, C6.2, C7.2, C8.2, C9.2, C10.2, C11.2, C12.2, C13.2, C14.2, C16.2, C17.2, C18.2, C20.2, D1.2, D4.C, D6.2, D6.5, E1.GND, J1.GND, J2.1, J3.1, J5.6, J8.1, J8.2, J9.C5, J11.1, JP4.1, JP5.1, L1.1, Q2.2, R1.1, R3.1, R4.1, S3.1, S3.2, S4.1, S4.2, U1.7, U2.2, U3.2, U4.2, U5.4, U5.EP, U6.1, U6.3, U6.5, U6.14, U6.20, U6.21, U6.22, U6.30, U6.32, U6.33, U6.43, U6.50, U6.54, U6.55, U6.57, U6.58, U6.59, U6.60, U6.61, U6.63, U6.64, U6.65, U6.66, U6.67, U6.68, U6.69, U6.70, U6.71, U6.72, U6.73, U6.74, U6.75, U6.76, U6.77, U6.78, U6.79, U6.80, U6.81, U6.82, U6.83, U6.84, U6.85, U6.86, U6.87, U6.88, U6.89, U6.90, U6.91, U6.92, U6.93, U6.94, U6.95, U6.96
GND1: B2.GND@0, B2.GND@1, B2.GND@2, C21.2, C22.2, C23.2, C24.2, C25.2, C26.2, C27.2, C28.2, C29.2, C30.2, C31.2, C34.2, C35.2, C36.2, C37.2, C38.2, C39.2, C40.2, D10.C, D11.2, D12.2, D12.5, E2.GND, J12.GND, J13.1, J14.1, J15.6, J16.C5, J17.1, J17.2, J22.1, JP13.1, JP14.1, L3.1, Q4.2, R9.1, R11.1, R16.1, S5.1, S5.2, S6.1, S6.2, U7.1, U7.3, U7.5, U7.14, U7.20, U7.21, U7.22, U7.30, U7.32, U7.33, U7.43, U7.50, U7.54, U7.55, U7.57, U7.58, U7.59, U7.60, U7.61, U7.63, U7.64, U7.65, U7.66, U7.67, U7.68, U7.69, U7.70, U7.71, U7.72, U7.73, U7.74, U7.75, U7.76, U7.77, U7.78, U7.79, U7.80, U7.81, U7.82, U7.83, U7.84, U7.85, U7.86, U7.87, U7.88, U7.89, U7.90, U7.91, U7.92, U7.93, U7.94, U7.95, U7.96, U8.2, U9.4, U9.EP, U10.2, U11.2, U12.7
GND2: B3.GND@0, B3.GND@1, B3.GND@2, C41.2, C42.2, C43.2, C44.2, C45.2, C46.2, C47.2, C48.2, C49.2, C50.2, C51.2, C54.2, C55.2, C56.2, C57.2, C58.2, C59.2, C60.2, D16.C, D17.2, D18.2, D18.5, E3.GND, J23.GND, J24.1, J25.1, J26.6, J27.C5, J28.1, J28.2, J33.1, JP21.1, JP22.1, L5.1, Q6.2, R17.1, R19.1, R24.1, S9.1, S9.2, S10.1, S10.2, U13.1, U13.3, U13.5, U13.14, U13.20, U13.21, U13.22, U13.30, U13.32, U13.33, U13.43, U13.50, U13.54, U13.55, U13.57, U13.58, U13.59, U13.60, U13.61, U13.63, U13.64, U13.65, U13.66, U13.67, U13.68, U13.69, U13.70, U13.71, U13.72, U13.73, U13.74, U13.75, U13.76, U13.77, U13.78, U13.79, U13.80, U13.81, U13.82, U13.83, U13.84, U13.85, U13.86, U13.87, U13.88, U13.89, U13.90, U13.91, U13.92, U13.93, U13.94, U13.95, U13.96, U14.2, U15.4, U15.EP, U16.2, U17.2, U18.7
GND3: B4.GND@0, B4.GND@1, B4.GND@2, C61.2, C62.2, C63.2, C64.2, C65.2, C66.2, C67.2, C68.2, C69.2, C70.2, C71.2, C74.2, C75.2, C76.2, C77.2, C78.2, C79.2, C80.2, D22.C, D23.2, D24.2, D24.5, E4.GND, J34.GND, J35.1, J36.1, J37.6, J38.C5, J39.1, J39.2, J44.1, JP29.1, JP30.1, L7.1, Q8.2, R25.1, R27.1, R32.1, S13.1, S13.2, S14.1, S14.2, U19.1, U19.3, U19.5, U19.14, U19.20, U19.21, U19.22, U19.30, U19.32, U19.33, U19.43, U19.50, U19.54, U19.55, U19.57, U19.58, U19.59, U19.60, U19.61, U19.63, U19.64, U19.65, U19.66, U19.67, U19.68, U19.69, U19.70, U19.71, U19.72, U19.73, U19.74, U19.75, U19.76, U19.77, U19.78, U19.79, U19.80, U19.81, U19.82, U19.83, U19.84, U19.85, U19.86, U19.87, U19.88, U19.89, U19.90, U19.91, U19.92, U19.93, U19.94, U19.95, U19.96, U20.2, U21.4, U21.EP, U22.2, U23.2, U24.7
GPIO1: R6.2, U6.16
GPIO2: R1.2, U2.3, U6.23
GPIO3: R13.2, U7.16
GPIO3-CELL: U1.2, U6.24
GPIO3-CELL1: U7.24, U12.2
GPIO3-CELL2: U13.24, U18.2
GPIO3-CELL3: U19.24, U24.2
GPIO3-QWIIC: J4.1, U1.13
GPIO3-QWIIC1: J20.1, U12.13
GPIO3-QWIIC2: J31.1, U18.13
GPIO3-QWIIC3: J42.1, U24.13
GPIO4: R16.2, U7.23, U10.3
GPIO5: R21.2, U13.16
GPIO6: R24.2, U13.23, U16.3
GPIO7: R29.2, U19.16
GPIO8: R32.2, U19.23, U22.3
GPS-3.3V: C3.1, J3.2, U2.5
GPS-3.3V1: C40.1, J13.2, U10.5
GPS-3.3V2: C60.1, J24.2, U16.5
GPS-3.3V3: C80.1, J35.2, U22.5
HARDRX-ARDUINO: B1.RX, S1.1
HARDRX-ARDUINO1: B2.RX, S8.1
HARDRX-ARDUINO2: B3.RX, S12.1
HARDRX-ARDUINO3: B4.RX, S16.1
HARDTX-ARDUINO: B1.TX, S1.4
HARDTX-ARDUINO1: B2.TX, S8.4
HARDTX-ARDUINO2: B3.TX, S12.4
HARDTX-ARDUINO3: B4.TX, S16.4
IOREF: B1.IOREF, C2.1, J5.4, JP1.2, U1.14, U4.7
IOREF1: B2.IOREF, C25.1, J15.4, JP12.2, U11.7, U12.14
IOREF2: B3.IOREF, C45.1, J26.4, JP20.2, U17.7, U18.14
IOREF3: B4.IOREF, C65.1, J37.4, JP28.2, U23.7, U24.14
unnamed: R3.2, U3.5
unnamed: D8.C, R10.2
unnamed: R10.1, U8.1
unnamed: R11.2, U8.5
unnamed: C31.1, L4.2, R12.2
unnamed: C32.2, C33.1, L3.2
unnamed: C16.1, L2.2, R8.2
unnamed: C15.2, C19.1, L1.2
unnamed: J8.FEED, JP8.2
unnamed: Q2.1, R6.1
unnamed: D1.1, J1.D-
unnamed: D5.C, R7.2
unnamed: D1.3, J1.D+
unnamed: Q2.3, R7.1
unnamed: D4.A, R5.1
unnamed: D2.C, R2.2
unnamed: R2.1, U3.1
unnamed: B1.D5, JP2.1
unnamed: B1.D6, JP3.1
unnamed: C19.2, JP7.1, JP8.1, L2.1
unnamed: E1.FEED, JP7.2
unnamed: J17.FEED, JP15.2
unnamed: Q4.1, R13.1
unnamed: D10.A, R15.1
unnamed: D9.C, R14.2
unnamed: Q4.3, R14.1
unnamed: B2.D5, JP11.1
unnamed: B2.D6, JP10.1
unnamed: C33.2, JP15.1, JP16.1, L4.1
unnamed: E2.FEED, JP16.2
unnamed: D11.1, J12.D-
unnamed: D11.3, J12.D+
unnamed: D14.C, R18.2
unnamed: R18.1, U14.1
unnamed: R19.2, U14.5
unnamed: C51.1, L6.2, R20.2
unnamed: C52.2, C53.1, L5.2
unnamed: J28.FEED, JP23.2
unnamed: Q6.1, R21.1
unnamed: D16.A, R23.1
unnamed: D15.C, R22.2
unnamed: Q6.3, R22.1
unnamed: B3.D5, JP19.1
unnamed: B3.D6, JP18.1
unnamed: C53.2, JP23.1, JP24.1, L6.1
unnamed: E3.FEED, JP24.2
unnamed: D17.1, J23.D-
unnamed: D17.3, J23.D+
unnamed: D20.C, R26.2
unnamed: R26.1, U20.1
unnamed: R27.2, U20.5
unnamed: C71.1, L8.2, R28.2
unnamed: C72.2, C73.1, L7.2
unnamed: J39.FEED, JP31.2
unnamed: Q8.1, R29.1
unnamed: D22.A, R31.1
unnamed: D21.C, R30.2
unnamed: Q8.3, R30.1
unnamed: B4.D5, JP27.1
unnamed: B4.D6, JP26.1
unnamed: C73.2, JP31.1, JP32.1, L8.1
unnamed: E4.FEED, JP32.2
unnamed: D23.1, J34.D-
unnamed: D23.3, J34.D+
PWR_ON: JP2.2, S3.3, S3.4, U6.15
PWR_ON1: JP11.2, S5.3, S5.4, U7.15
PWR_ON2: JP19.2, S9.3, S9.4, U13.15
PWR_ON3: JP27.2, S13.3, S13.4, U19.15
RESET_N: JP3.2, S4.3, S4.4, U6.18
RESET_N1: JP10.2, S6.3, S6.4, U7.18
RESET_N2: JP18.2, S10.3, S10.4, U13.18
RESET_N3: JP26.2, S14.3, S14.4, U19.18
RI: J7.1, U6.7
RI1: J19.1, U7.7
RI2: J30.1, U13.7
RI3: J41.1, U19.7
RTS: J6.3, JP4.2, U6.10
RTS1: J18.3, JP14.2, U7.10
RTS2: J29.3, JP22.2, U13.10
RTS3: J40.3, JP30.2, U19.10
RX-ARDUINO: J5.2, S1.2, U1.12
RX-ARDUINO1: J15.2, S8.2, U12.12
RX-ARDUINO2: J26.2, S12.2, U18.12
RX-ARDUINO3: J37.2, S16.2, U24.12
RX-CELL: U1.4, U6.12
RX-CELL1: U7.12, U12.4
RX-CELL2: U13.12, U18.4
RX-CELL3: U19.12, U24.4
SCL-CELL: U4.5, U6.27
SCL-CELL1: U7.27, U11.5
SCL-CELL2: U13.27, U17.5
SCL-CELL3: U19.27, U23.5
SCL-QWIIC: J3.4, J10.2, U4.8
SCL-QWIIC1: J13.4, J21.2, U11.8
SCL-QWIIC2: J24.4, J32.2, U17.8
SCL-QWIIC3: J35.4, J43.2, U23.8
SDA-CELL: U4.4, U6.26
SDA-CELL1: U7.26, U11.4
SDA-CELL2: U13.26, U17.4
SDA-CELL3: U19.26, U23.4
SDA-QWIIC: J3.3, J10.1, U4.1
SDA-QWIIC1: J13.3, J21.1, U11.1
SDA-QWIIC2: J24.3, J32.1, U17.1
SDA-QWIIC3: J35.3, J43.1, U23.1
SHIELD: J1.SHIELD, J1.SHIELD2, J1.SHIELD3, J1.SHIELD4, J1.SHIELD5, J1.SHIELD6, J1.SHIELD7, J1.SHIELD8, J1.SHIELD9, J1.SHIELD10
SHIELD1: J12.SHIELD, J12.SHIELD2, J12.SHIELD3, J12.SHIELD4, J12.SHIELD5, J12.SHIELD6, J12.SHIELD7, J12.SHIELD8, J12.SHIELD9, J12.SHIELD10
SHIELD2: J23.SHIELD, J23.SHIELD2, J23.SHIELD3, J23.SHIELD4, J23.SHIELD5, J23.SHIELD6, J23.SHIELD7, J23.SHIELD8, J23.SHIELD9, J23.SHIELD10
SHIELD3: J34.SHIELD, J34.SHIELD2, J34.SHIELD3, J34.SHIELD4, J34.SHIELD5, J34.SHIELD6, J34.SHIELD7, J34.SHIELD8, J34.SHIELD9, J34.SHIELD10
SIM_CLK: C18.1, D6.6, J9.C3, U6.38
SIM_CLK1: C27.1, D12.6, J16.C3, U7.38
SIM_CLK2: C47.1, D18.6, J27.C3, U13.38
SIM_CLK3: C67.1, D24.6, J38.C3, U19.38
SIM_IO: C17.1, D6.4, J9.C7, U6.39
SIM_IO1: C28.1, D12.4, J16.C7, U7.39
SIM_IO2: C48.1, D18.4, J27.C7, U13.39
SIM_IO3: C68.1, D24.4, J38.C7, U19.39
SIM_RST: C20.1, D6.3, J9.C2, U6.40
SIM_RST1: C26.1, D12.3, J16.C2, U7.40
SIM_RST2: C46.1, D18.3, J27.C2, U13.40
SIM_RST3: C66.1, D24.3, J38.C2, U19.40
SOFTRX-ARDUINO: B1.D8, S1.3
SOFTRX-ARDUINO1: B2.D8, S8.3
SOFTRX-ARDUINO2: B3.D8, S12.3
SOFTRX-ARDUINO3: B4.D8, S16.3
SOFTTX-ARDUINO: B1.D9, S1.6
SOFTTX-ARDUINO1: B2.D9, S8.6
SOFTTX-ARDUINO2: B3.D9, S12.6
SOFTTX-ARDUINO3: B4.D9, S16.6
TX-ARDUINO: J5.3, S1.5, U1.11
TX-ARDUINO1: J15.3, S8.5, U12.11
TX-ARDUINO2: J26.3, S12.5, U18.11
TX-ARDUINO3: J37.3, S16.5, U24.11
TX-CELL: U1.3, U6.13
TX-CELL1: U7.13, U12.3
TX-CELL2: U13.13, U18.3
TX-CELL3: U19.13, U24.3
VIN: C6.1, D3.C, Q1.2, S2.1, S2.4, U5.5, U5.8
VIN1: C22.1, D7.C, Q3.2, S7.1, S7.4, U9.5, U9.8
VIN2: C42.1, D13.C, Q5.2, S11.1, S11.4, U15.5, U15.8
VIN3: C62.1, D19.C, Q7.2, S15.1, S15.4, U21.5, U21.8
VSIM: C13.1, C14.1, D6.1, J9.C1, U6.41
VSIM1: C29.1, C30.1, D12.1, J16.C1, U7.41
VSIM2: C49.1, C50.1, D18.1, J27.C1, U13.41
VSIM3: C69.1, C70.1, D24.1, J38.C1, U19.41
VUSB_DET: JP6.2, U6.17
VUSB_DET1: JP9.2, U7.17
VUSB_DET2: JP17.2, U13.17
VUSB_DET3: JP25.2, U19.17
V_BATT: C5.1, J2.2, J11.2, Q1.3, U3.3
V_BATT1: C21.1, J14.2, J22.2, Q3.3, U8.3
V_BATT2: C41.1, J25.2, J33.2, Q5.3, U14.3
V_BATT3: C61.1, J36.2, J44.2, Q7.3, U20.3
V_USB: D1.5, D2.A, D3.A, J1.VBUS, JP6.1, Q1.1, R4.2, S2.3, S2.6, U3.4
V_USB1: D7.A, D8.A, D11.5, J12.VBUS, JP9.1, Q3.1, R9.2, S7.3, S7.6, U8.4
V_USB2: D13.A, D14.A, D17.5, J23.VBUS, JP17.1, Q5.1, R17.2, S11.3, S11.6, U14.4
V_USB3: D19.A, D20.A, D23.5, J34.VBUS, JP25.1, Q7.1, R25.2, S15.3, S15.6, U20.4

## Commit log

2018-08-15 Initial commit of hardware.
    [lte_cat_m1_shield_sara-r4.brd, lte_cat_m1_shield_sara-r4.sch]
2018-08-15 Minor revisions post-review
    [lte_cat_m1_shield_sara-r4.brd, lte_cat_m1_shield_sara-r4.sch]
2018-08-22 hardware revisions post u-blox review - x02 production hardware
    [lte_cat_m1_shield_sara-r4-Panel.GBL, lte_cat_m1_shield_sara-r4-Panel.GBO, lte_cat_m1_shield_sara-r4-Panel.GBP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]
2018-09-13 v10 of the LTE Shield hardware.
    [lte_cat_m1_shield_sara-r4.brd, lte_cat_m1_shield_sara-r4.sch]
2018-09-14 Removing single-board gerber files.
    [lte_cat_m1_shield_sara-r4.GBL, lte_cat_m1_shield_sara-r4.GBO, lte_cat_m1_shield_sara-r4.GBP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]
2018-09-14 DNP'ing the antenna-detect circuit.
    [lte_cat_m1_shield_sara-r4.brd, lte_cat_m1_shield_sara-r4.sch]
2018-09-14 Revisions post-checklist.
    [lte_cat_m1_shield_sara-r4.brd, lte_cat_m1_shield_sara-r4.sch]
2018-09-14 Adding production IDs to new parts.
    [lte_cat_m1_shield_sara-r4.brd, lte_cat_m1_shield_sara-r4.sch]
2018-09-14 Modification post-group-review. Labels, Qwiic breakouts, test points.
    [lte_cat_m1_shield_sara-r4.brd, lte_cat_m1_shield_sara-r4.sch]
2018-09-18 Revising product name in silk, schematic fixes.
    [lte_cat_m1_shield_sara-r4.brd, lte_cat_m1_shield_sara-r4.sch]
2018-09-18 panel v10 created
    [14099-lte_cat_m1_shield_sara-r4-Panel.GBL, 14099-lte_cat_m1_shield_sara-r4-Panel.GBO, 14099-lte_cat_m1_shield_sara-r4-Panel.GBS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]
2019-12-09 Disconnected AREF from GND
    [lte_cat_m1_shield_sara-r4.brd, lte_cat_m1_shield_sara-r4.sch]
2019-12-13 Production panel v11
    Also updated sch pdf
    [14099-lte_cat_m1_shield_sara-r4-Panel.GBL, 14099-lte_cat_m1_shield_sara-r4-Panel.GBO, 14099-lte_cat_m1_shield_sara-r4-Panel.GBS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]

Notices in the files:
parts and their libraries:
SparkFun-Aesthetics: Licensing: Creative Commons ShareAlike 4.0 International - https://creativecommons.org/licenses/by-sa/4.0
